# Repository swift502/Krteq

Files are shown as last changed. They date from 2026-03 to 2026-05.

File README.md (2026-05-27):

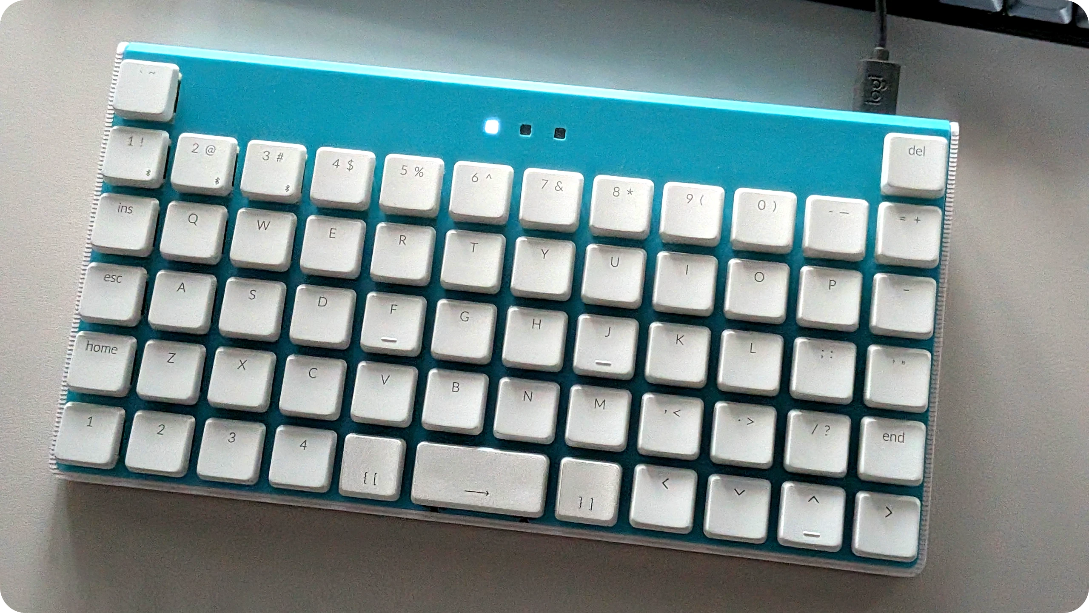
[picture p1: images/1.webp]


# Krteq





An extended 5x12 keyboard with 2 extra keys. Intended for ortho layouts with a shifted number row, allowing for the placement of the delete and tilde keys above their usual spots.

Krteq is a successor to [Krtkus](https://github.com/swift502/Krtkus), learning from its lessons to make a design that's easier to build, more maintainable, better encapsulated and overall a more complete product.

### Features

- Low profile
- Hotswap
- White backlight (only breathing effect)
- QMK/VIA compatible
- Gateron KS-33B (GLP 3.0) switches
- 3D printed case with a 7 degree tilt
- Tray mount PCB, integrated plate
- 233mm × 125mm × 30mm

Connecting the keyboard to [usevia.app](https://usevia.app) requires manually uploading the [design file](production/krteq_via.json) in the design tab.

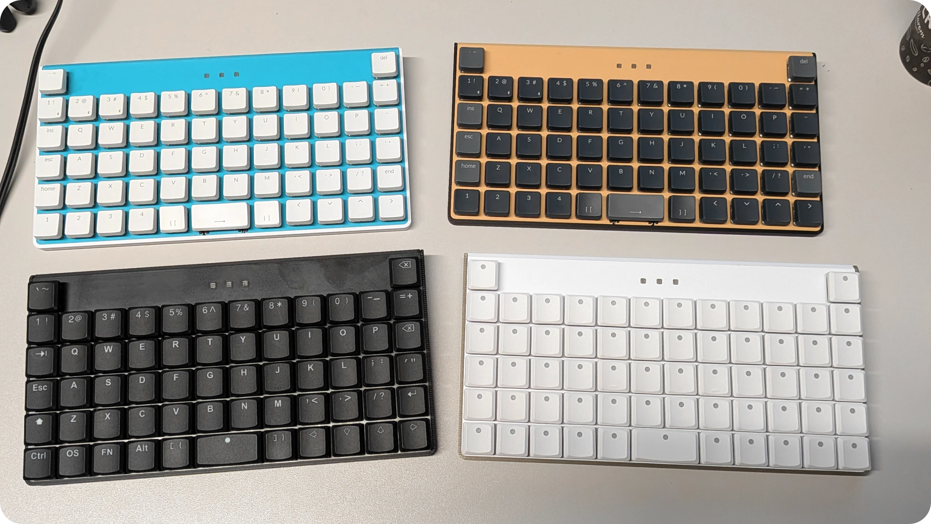
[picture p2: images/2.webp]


## PCB

The Kicad 10 project can be found in [source/kicad](source/kicad). All parts are SMD. The PCB is intended to be ordered pre-assembled for an easier, although more expensive build process.

To generate fabrication files, open the Kicad project and use an export plugin provided by one of the PCB manufacturers you want to order from. The order process is then highly dependent on the manufacturer.

Suggested resistor values correspond to max safe LED brightness, which is later adjusted using software. Backlight intensity is controlled by QMK's backlight system, and indicator brightness is adjustable via custom PWM code.

### Suggested BOM

| Part | Manufacturer Part Number |
|---|---|
| Switch Diode | 1N4148W |
| Backlight LED | MHT151WDT |
| GSD NMOS | HX2302A |
| R82Ω | 0603WAF820JT5E |
| R330Ω | 0603WAF3300T5E |
| R470Ω | 0603WAF4700T5E |
| R10kΩ | 0603WAF1002T5E |
| Switch socket | CPG151101S11-16 |

## Case

Case is designed non-destructively in Blender here [source/Krteq.blend](source/Krteq.blend), so it should be fairly easy to modify if needed. STL files for 3D printing can be found in [production/stl](production/stl). Tested with PLA, 0.15mm layer height, 100% infill.

You'll need to print at least 3 files. Top and bottom in one or two colors, and the LED cover strip using transparent filament.

The top part also has a "keychron" variant, which adjusts stabilizer cutouts for their non-standard [triangular stem design](https://www.keychron.com/blogs/news/the-design-details-of-our-keychron-low-profile-keyboard-stabilizers).

## Firmware

A pre-compiled firmware file can be found here [production/krteq_firmware.uf2](production/krteq_firmware.uf2).

QMK/VIA setup with a few custom features:

- custom `KRT_VOL` keycode for combined volume control
- pressing <kbd>LShift</kbd> + <kbd>RShift</kbd> + <kbd>B</kbd> enters bootloader mode
- pressing <kbd>LShift</kbd> + <kbd>RShift</kbd> + <kbd>C</kbd> reverts to the default keymap

### Compiling (Windows)

Install:

- Python: https://www.python.org/
- MSYS: https://msys.qmk.fm

Run the compile script:

```sh
python source/scripts/qmk_compile.py
```

### Flashing (Windows)

For the initial flash, hold the BOOTSEL button while connecting the Pico to a computer to have it show up as a storage device, then copy the compiled [firmware file](production/krteq_firmware.uf2) over to it.

Once flashed, you can trigger the bootloader mode again by simply pressing the <kbd>LShift</kbd> + <kbd>RShift</kbd> + <kbd>B</kbd> key combination.

## Build guide

### Parts

- [PCB](#pcb)
- [Case](#case)
- Raspberry Pi Pico
- 30cm (1ft) USB panel-mount extension cable
- 61x Gateron KS-33B (GLP 3.0) switches
- 61x MX low profile keycaps
- Gateron 2u low profile plate-mounted stabilizer
- 3x M2x6 flat head screw
- Rubber feet

### Assembly

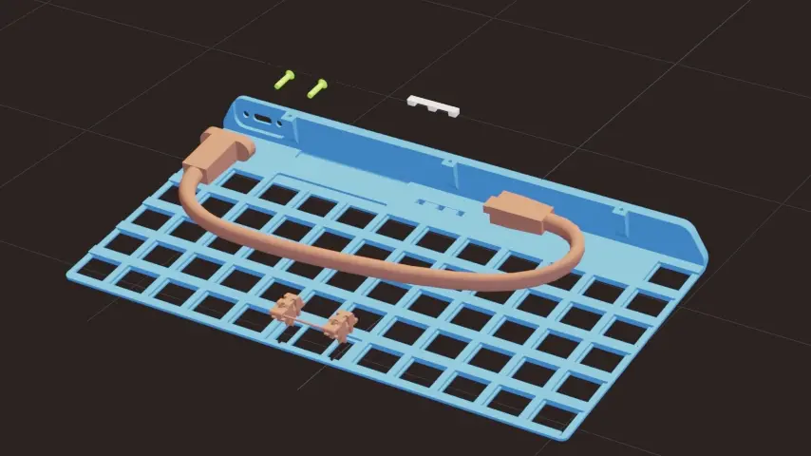
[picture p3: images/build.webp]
(https://youtu.be/iH0en77GBfo)


Assuming you get the PCB pre-assembled, the only thing left to solder is the MCU. I recommend using a socket header for easy Pico replacement, but it can obviously be soldered directly as well.

1. Install the Pico onto the PCB (socketed or soldered)
2. Attach the indicator LED cover strip to the top case
3. Attach the 2u stabilizer to the top case
4. Push the corner switches through the top case and into the PCB sockets to hold the two parts together
5. Screw the panel mount cable to the case cutout and connect the other end to the Pico

> [!IMPORTANT]
> Now is your last chance to perform the initial [firmware flash](#flashing-windows). After this point the BOOTSEL button won't be accessible. I also recommend plugging the keyboard in and testing basic functionality. If you find an issue, it's still very easy to test connectivity or swap out the Pico.

6. Slide the top assembly into the bottom case rails
7. Screw the top and bottom cases together
8. Install the remaining switches and keycaps

And you're done!

## QnA

### Why the unusual KS-33B switches?

The idea was that ordering a pre-assembled PCB will be faster, cheaper and long-term more viable if it involves regular hotswap sockets, since they're always in stock and available in cheaper off-brand variants, unlike the Gateron low profile hotswap sockets, which are much less common. The fact that they also support regular MX switches is a nice bonus.

### So is this board compatible with high profile switches?

Footprint-wise, yes, but a compatible high-profile top case variant would have to be made, and I have no idea if the low profile stabilizer would be compatible with regular keycaps. So there's a few concerns, but theoretically it's possible.

### Why no RGB?

The simple backlighting was a lot safer and easier to implement. But now that I've confirmed it works, I'd love to implement proper RGB with all effects for the next revision.

### Who needs scroll lock?

I really wanted an LED for my custom letter accent input method. I wanted it to be an actual compose LED, which would be supported by QMK, but unfortunately not Windows. So ultimately the third LED ended up being a regular scroll lock. I use it as an indicator for my custom accent input method, but generally like it as a general purpose LED that can be used for custom functionality via AHK scripts.

## Documentation

### QMK

- Info.json: https://docs.qmk.fm/reference_info_json
- Keycodes: https://docs.qmk.fm/keycodes
- Default keymap: https://docs.qmk.fm/configurator_default_keymaps
- Backlight: https://docs.qmk.fm/features/backlight

### Kicad

Switch grid reference table:

| Grid | Size |
| --- | --- |
| Switch 1 | 19.05 |
| Switch 1/4 | 4.7625 |
| Switch 1/16 | 1.190625 |
| Switch 1/32 | 0.5953125 |
| Switch 1/64 | 0.29765625 |

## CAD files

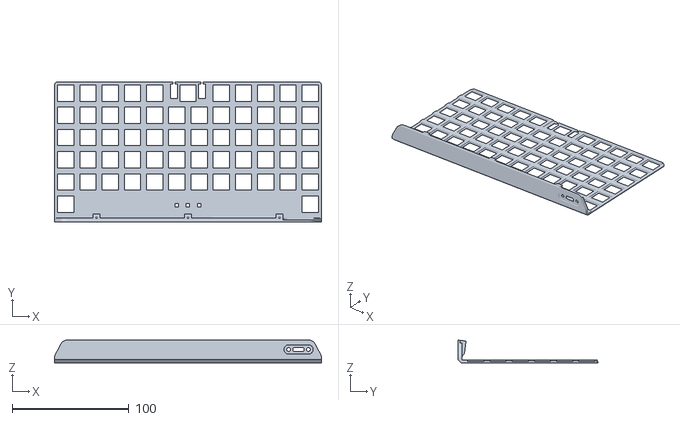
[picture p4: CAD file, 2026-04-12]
production/stl/top_keychron.stl
229.0 x 120.5 x 19.6

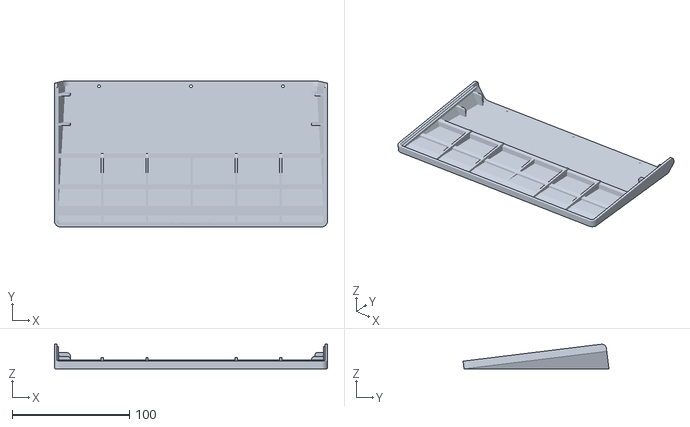
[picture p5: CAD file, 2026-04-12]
production/stl/bottom.stl
233.0 x 124.5 x 21.0

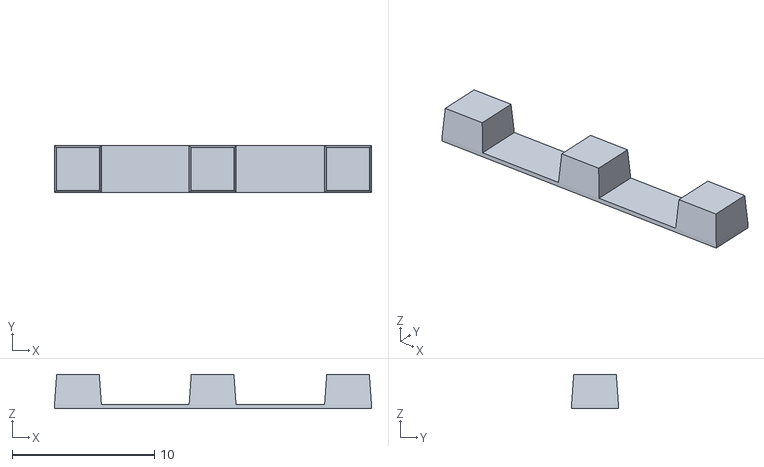
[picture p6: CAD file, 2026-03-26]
production/stl/led.stl
22.3 x 3.30 x 2.40

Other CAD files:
production/stl/top.stl
source/Krteq.blend

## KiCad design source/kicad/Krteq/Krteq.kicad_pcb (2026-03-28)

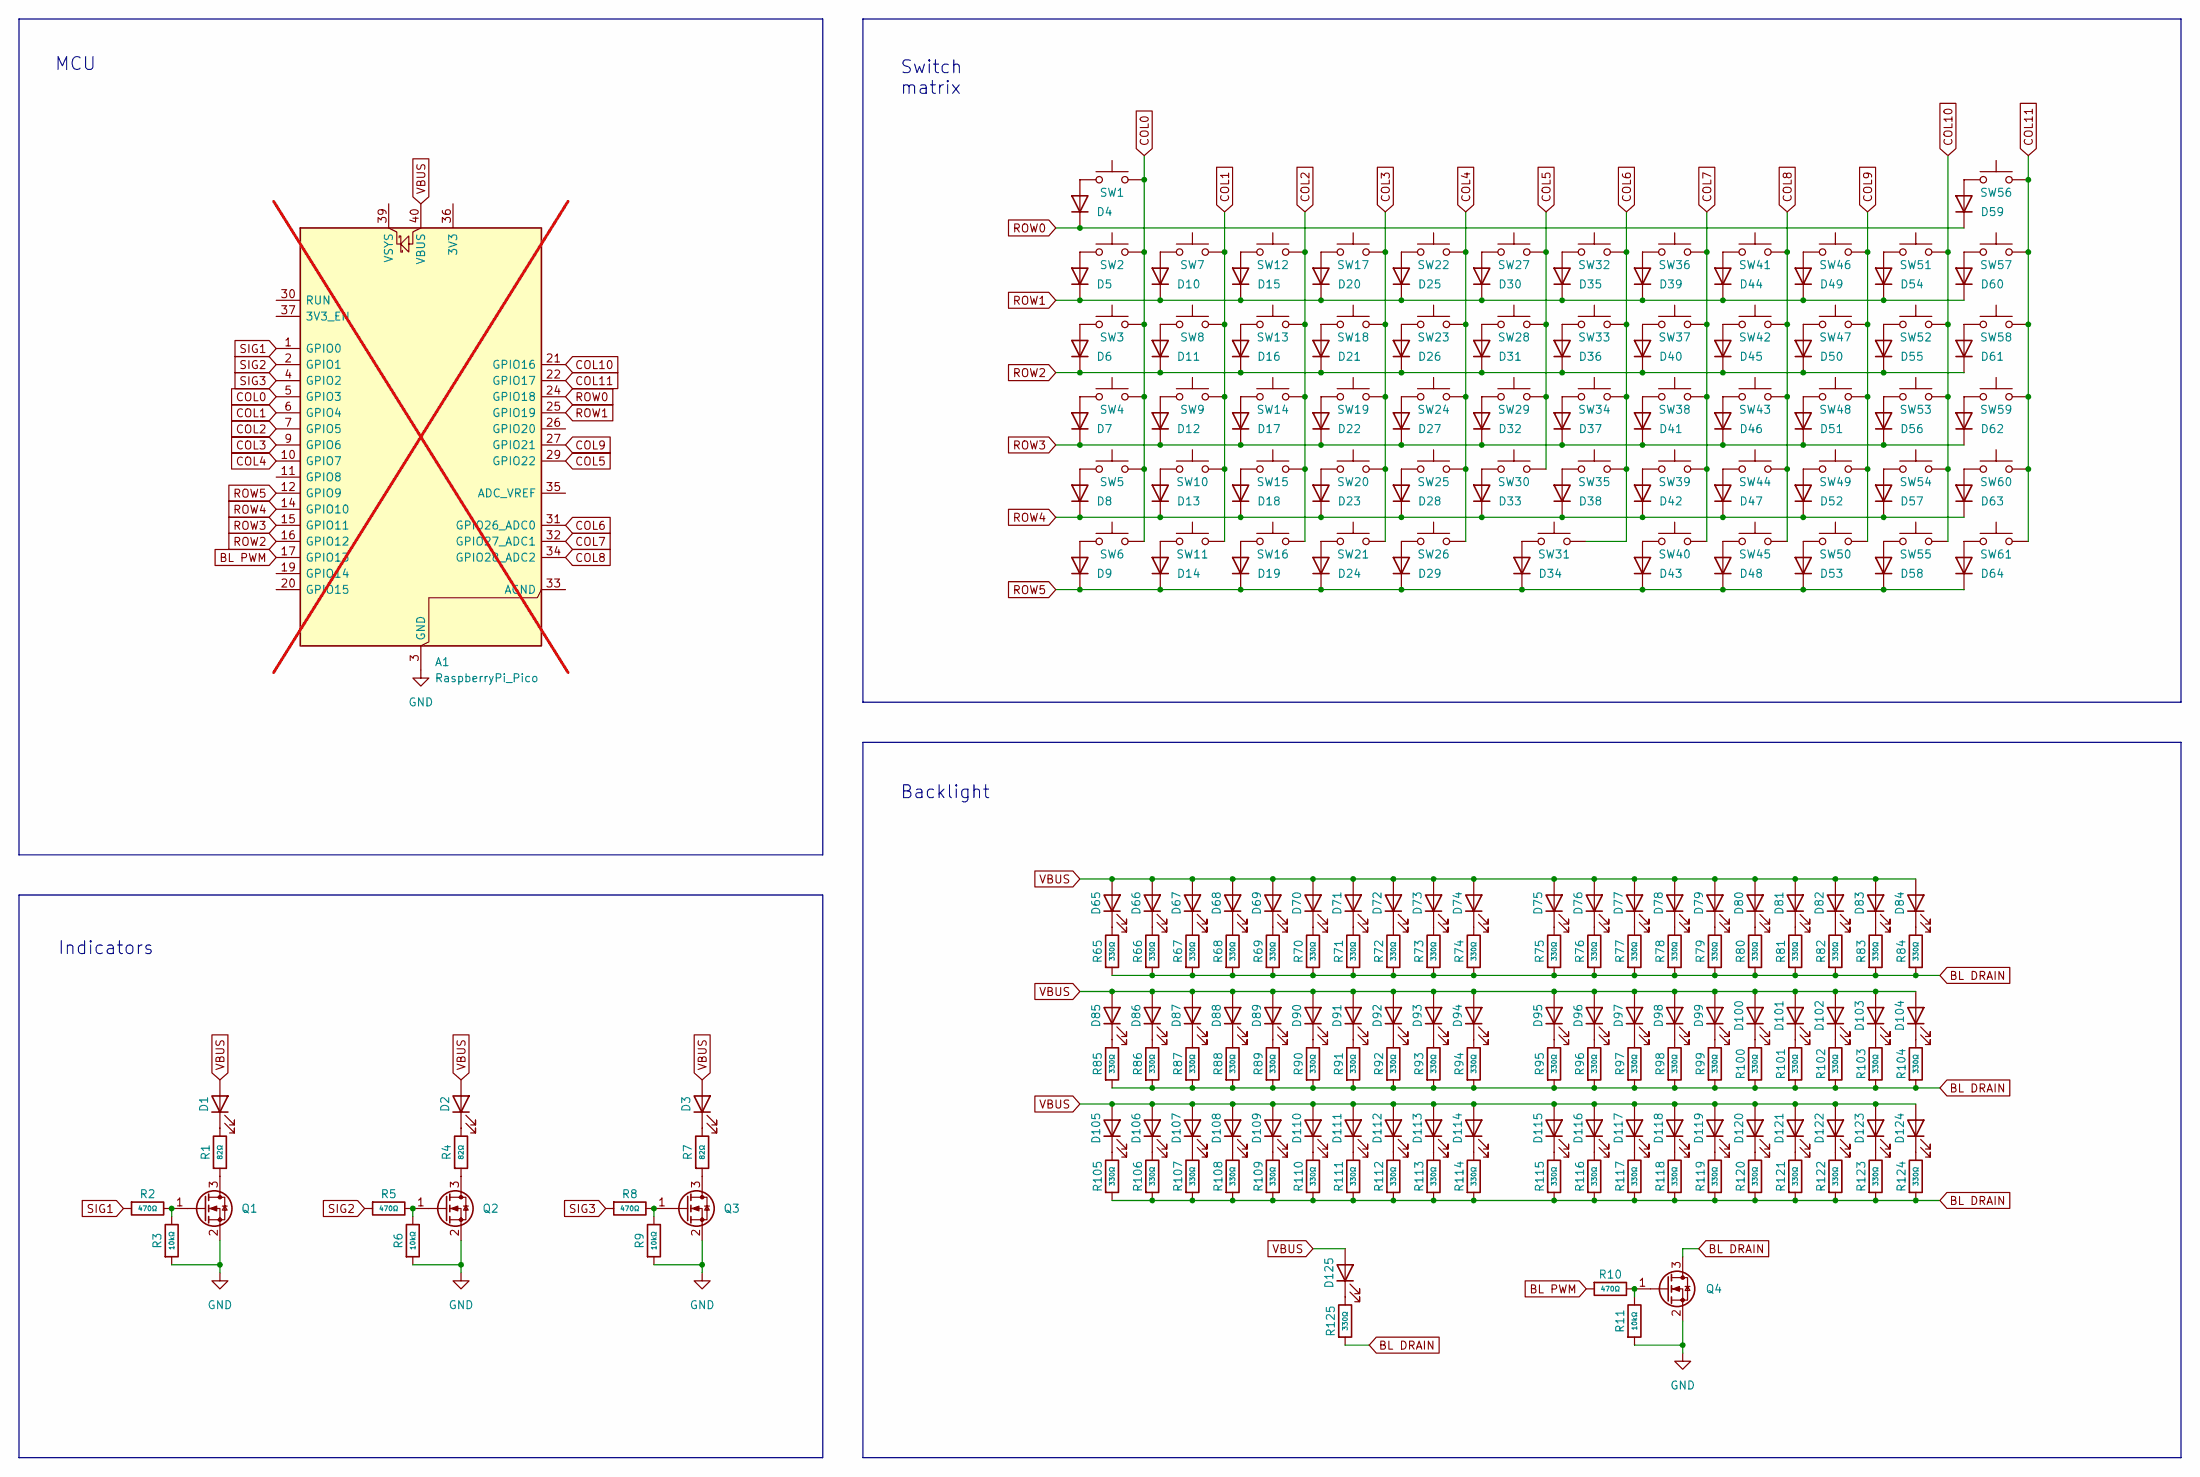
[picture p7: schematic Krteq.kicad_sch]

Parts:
A1: RaspberryPi_Pico; Raspberry Pi Pico; not fitted
D1, D2, D3, D65, D66, D67, D68, D69, D70, D71, D72, D73, D74, D75, D76, D77, D78, D79, D80, D81, D82, D83, D84, D85, D86, D87, D88, D89, D90, D91, D92, D93, D94, D95, D96, D97, D98, D99, D100, D101, D102, D103, D104, D105, D106, D107, D108, D109, D110, D111, D112, D113, D114, D115, D116, D117, D118, D119, D120, D121, D122, D123, D124, D125: LED; MHT151WDT; MPN MHT151WDT
D4, D5, D6, D7, D8, D9, D10, D11, D12, D13, D14, D15, D16, D17, D18, D19, D20, D21, D22, D23, D24, D25, D26, D27, D28, D29, D30, D31, D32, D33, D34, D35, D36, D37, D38, D39, D40, D41, D42, D43, D44, D45, D46, D47, D48, D49, D50, D51, D52, D53, D54, D55, D56, D57, D58, D59, D60, D61, D62, D63, D64: Diode; D_SOD-123; MPN 1N4148W
Q1, Q2, Q3, Q4: Q NMOS GSD; SOT-23; MPN HX2302A
R1, R4, R7: 82Ω; R_0603_1608Metric; MPN 0603WAF820JT5E
R2, R5, R8, R10: 470Ω; R_0603_1608Metric; MPN 0603WAF4700T5E
R3, R6, R9, R11: 10kΩ; R_0603_1608Metric; MPN 0603WAF1002T5E
R65, R66, R67, R68, R69, R70, R71, R72, R73, R74, R75, R76, R77, R78, R79, R80, R81, R82, R83, R84, R85, R86, R87, R88, R89, R90, R91, R92, R93, R94, R95, R96, R97, R98, R99, R100, R101, R102, R103, R104, R105, R106, R107, R108, R109, R110, R111, R112, R113, R114, R115, R116, R117, R118, R119, R120, R121, R122, R123, R124, R125: 330Ω; R_0603_1608Metric; MPN 0603WAF3300T5E
SW1, SW2, SW3, SW4, SW5, SW6, SW7, SW8, SW9, SW10, SW11, SW12, SW13, SW14, SW15, SW16, SW17, SW18, SW19, SW20, SW21, SW22, SW23, SW24, SW25, SW26, SW27, SW28, SW29, SW30, SW32, SW33, SW34, SW35, SW36, SW37, SW38, SW39, SW40, SW41, SW42, SW43, SW44, SW45, SW46, SW47, SW48, SW49, SW50, SW51, SW52, SW53, SW54, SW55, SW56, SW57, SW58, SW59, SW60, SW61: Switch; KS-33B Hotswap 1u; MPN CPG151101S11-16
SW31: Switch; KS-33B Hotswap 2u; MPN CPG151101S11-16

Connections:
BL DRAIN: Q4.3 (D), R65.2, R66.2, R67.2, R68.2, R69.2, R70.2, R71.2, R72.2, R73.2, R74.2, R75.2, R76.2, R77.2, R78.2, R79.2, R80.2, R81.2, R82.2, R83.2, R84.2, R85.2, R86.2, R87.2, R88.2, R89.2, R90.2, R91.2, R92.2, R93.2, R94.2, R95.2, R96.2, R97.2, R98.2, R99.2, R100.2, R101.2, R102.2, R103.2, R104.2, R105.2, R106.2, R107.2, R108.2, R109.2, R110.2, R111.2, R112.2, R113.2, R114.2, R115.2, R116.2, R117.2, R118.2, R119.2, R120.2, R121.2, R122.2, R123.2, R124.2, R125.2
BL PWM: A1.17 (GPIO13), R10.2
COL0: A1.5 (GPIO3), SW1.2, SW2.2, SW3.2, SW4.2, SW5.2, SW6.2
COL1: A1.6 (GPIO4), SW7.2, SW8.2, SW9.2, SW10.2, SW11.2
COL2: A1.7 (GPIO5), SW12.2, SW13.2, SW14.2, SW15.2, SW16.2
COL3: A1.9 (GPIO6), SW17.2, SW18.2, SW19.2, SW20.2, SW21.2
COL4: A1.10 (GPIO7), SW22.2, SW23.2, SW24.2, SW25.2, SW26.2
COL5: A1.29 (GPIO22), SW27.2, SW28.2, SW29.2, SW30.2
COL6: A1.31 (GPIO26_ADC0), SW31.2, SW32.2, SW33.2, SW34.2, SW35.2
COL7: A1.32 (GPIO27_ADC1), SW36.2, SW37.2, SW38.2, SW39.2, SW40.2
COL8: A1.34 (GPIO28_ADC2), SW41.2, SW42.2, SW43.2, SW44.2, SW45.2
COL9: A1.27 (GPIO21), SW46.2, SW47.2, SW48.2, SW49.2, SW50.2
COL10: A1.21 (GPIO16), SW51.2, SW52.2, SW53.2, SW54.2, SW55.2
COL11: A1.22 (GPIO17), SW56.2, SW57.2, SW58.2, SW59.2, SW60.2, SW61.2
GND: A1.3 (GND), A1.8 (GND), A1.13 (GND), A1.18 (GND), A1.23 (GND), A1.28 (GND), A1.38 (GND), Q1.2 (S), Q2.2 (S), Q3.2 (S), Q4.2 (S), R3.2, R6.2, R9.2, R11.2
unnamed: D1.1 (K), R1.1
unnamed: D2.1 (K), R4.1
unnamed: D3.1 (K), R7.1
unnamed: D4.2 (A), SW1.1
unnamed: D5.2 (A), SW2.1
unnamed: D6.2 (A), SW3.1
unnamed: D7.2 (A), SW4.1
unnamed: D8.2 (A), SW5.1
unnamed: D9.2 (A), SW6.1
unnamed: D10.2 (A), SW7.1
unnamed: D11.2 (A), SW8.1
unnamed: D12.2 (A), SW9.1
unnamed: D13.2 (A), SW10.1
unnamed: D14.2 (A), SW11.1
unnamed: D15.2 (A), SW12.1
unnamed: D16.2 (A), SW13.1
unnamed: D17.2 (A), SW14.1
unnamed: D18.2 (A), SW15.1
unnamed: D19.2 (A), SW16.1
unnamed: D20.2 (A), SW17.1
unnamed: D21.2 (A), SW18.1
unnamed: D22.2 (A), SW19.1
unnamed: D23.2 (A), SW20.1
unnamed: D24.2 (A), SW21.1
unnamed: D25.2 (A), SW22.1
unnamed: D26.2 (A), SW23.1
unnamed: D27.2 (A), SW24.1
unnamed: D28.2 (A), SW25.1
unnamed: D29.2 (A), SW26.1
unnamed: D30.2 (A), SW27.1
unnamed: D31.2 (A), SW28.1
unnamed: D32.2 (A), SW29.1
unnamed: D33.2 (A), SW30.1
unnamed: D34.2 (A), SW31.1
unnamed: D35.2 (A), SW32.1
unnamed: D36.2 (A), SW33.1
unnamed: D37.2 (A), SW34.1
unnamed: D38.2 (A), SW35.1
unnamed: D39.2 (A), SW36.1
unnamed: D40.2 (A), SW37.1
unnamed: D41.2 (A), SW38.1
unnamed: D42.2 (A), SW39.1
unnamed: D43.2 (A), SW40.1
unnamed: D44.2 (A), SW41.1
unnamed: D45.2 (A), SW42.1
unnamed: D46.2 (A), SW43.1
unnamed: D47.2 (A), SW44.1
unnamed: D48.2 (A), SW45.1
unnamed: D49.2 (A), SW46.1
unnamed: D50.2 (A), SW47.1
unnamed: D51.2 (A), SW48.1
unnamed: D52.2 (A), SW49.1
unnamed: D53.2 (A), SW50.1
unnamed: D54.2 (A), SW51.1
unnamed: D55.2 (A), SW52.1
unnamed: D56.2 (A), SW53.1
unnamed: D57.2 (A), SW54.1
unnamed: D58.2 (A), SW55.1
unnamed: D59.2 (A), SW56.1
unnamed: D60.2 (A), SW57.1
unnamed: D61.2 (A), SW58.1
unnamed: D62.2 (A), SW59.1
unnamed: D63.2 (A), SW60.1
unnamed: D64.2 (A), SW61.1
unnamed: D65.1 (K), R65.1
unnamed: D66.1 (K), R66.1
unnamed: D67.1 (K), R67.1
unnamed: D68.1 (K), R68.1
unnamed: D69.1 (K), R69.1
unnamed: D70.1 (K), R70.1
unnamed: D71.1 (K), R71.1
unnamed: D72.1 (K), R72.1
unnamed: D73.1 (K), R73.1
unnamed: D74.1 (K), R74.1
unnamed: D75.1 (K), R75.1
unnamed: D76.1 (K), R76.1
unnamed: D77.1 (K), R77.1
unnamed: D78.1 (K), R78.1
unnamed: D79.1 (K), R79.1
unnamed: D80.1 (K), R80.1
unnamed: D81.1 (K), R81.1
unnamed: D82.1 (K), R82.1
unnamed: D83.1 (K), R83.1
unnamed: D84.1 (K), R84.1
unnamed: D85.1 (K), R85.1
unnamed: D86.1 (K), R86.1
unnamed: D87.1 (K), R87.1
unnamed: D88.1 (K), R88.1
unnamed: D89.1 (K), R89.1
unnamed: D90.1 (K), R90.1
unnamed: D91.1 (K), R91.1
unnamed: D92.1 (K), R92.1
unnamed: D93.1 (K), R93.1
unnamed: D94.1 (K), R94.1
unnamed: D95.1 (K), R95.1
unnamed: D96.1 (K), R96.1
unnamed: D97.1 (K), R97.1
unnamed: D98.1 (K), R98.1
unnamed: D99.1 (K), R99.1
unnamed: D100.1 (K), R100.1
unnamed: D101.1 (K), R101.1
unnamed: D102.1 (K), R102.1
unnamed: D103.1 (K), R103.1
unnamed: D104.1 (K), R104.1
unnamed: D105.1 (K), R105.1
unnamed: D106.1 (K), R106.1
unnamed: D107.1 (K), R107.1
unnamed: D108.1 (K), R108.1
unnamed: D109.1 (K), R109.1
unnamed: D110.1 (K), R110.1
unnamed: D111.1 (K), R111.1
unnamed: D112.1 (K), R112.1
unnamed: D113.1 (K), R113.1
unnamed: D114.1 (K), R114.1
unnamed: D115.1 (K), R115.1
unnamed: D116.1 (K), R116.1
unnamed: D117.1 (K), R117.1
unnamed: D118.1 (K), R118.1
unnamed: D119.1 (K), R119.1
unnamed: D120.1 (K), R120.1
unnamed: D121.1 (K), R121.1
unnamed: D122.1 (K), R122.1
unnamed: D123.1 (K), R123.1
unnamed: D124.1 (K), R124.1
unnamed: D125.1 (K), R125.1
unnamed: Q1.3 (D), R1.2
unnamed: Q1.1 (G), R2.1, R3.1
unnamed: Q2.3 (D), R4.2
unnamed: Q2.1 (G), R5.1, R6.1
unnamed: Q3.3 (D), R7.2
unnamed: Q3.1 (G), R8.1, R9.1
unnamed: Q4.1 (G), R10.1, R11.1
ROW0: A1.24 (GPIO18), D4.1 (K), D59.1 (K)
ROW1: A1.25 (GPIO19), D5.1 (K), D10.1 (K), D15.1 (K), D20.1 (K), D25.1 (K), D30.1 (K), D35.1 (K), D39.1 (K), D44.1 (K), D49.1 (K), D54.1 (K), D60.1 (K)
ROW2: A1.16 (GPIO12), D6.1 (K), D11.1 (K), D16.1 (K), D21.1 (K), D26.1 (K), D31.1 (K), D36.1 (K), D40.1 (K), D45.1 (K), D50.1 (K), D55.1 (K), D61.1 (K)
ROW3: A1.15 (GPIO11), D7.1 (K), D12.1 (K), D17.1 (K), D22.1 (K), D27.1 (K), D32.1 (K), D37.1 (K), D41.1 (K), D46.1 (K), D51.1 (K), D56.1 (K), D62.1 (K)
ROW4: A1.14 (GPIO10), D8.1 (K), D13.1 (K), D18.1 (K), D23.1 (K), D28.1 (K), D33.1 (K), D38.1 (K), D42.1 (K), D47.1 (K), D52.1 (K), D57.1 (K), D63.1 (K)
ROW5: A1.12 (GPIO9), D9.1 (K), D14.1 (K), D19.1 (K), D24.1 (K), D29.1 (K), D34.1 (K), D43.1 (K), D48.1 (K), D53.1 (K), D58.1 (K), D64.1 (K)
SIG1: A1.1 (GPIO0), R2.2
SIG2: A1.2 (GPIO1), R5.2
SIG3: A1.4 (GPIO2), R8.2
VBUS: A1.40 (VBUS), D1.2 (A), D2.2 (A), D3.2 (A), D65.2 (A), D66.2 (A), D67.2 (A), D68.2 (A), D69.2 (A), D70.2 (A), D71.2 (A), D72.2 (A), D73.2 (A), D74.2 (A), D75.2 (A), D76.2 (A), D77.2 (A), D78.2 (A), D79.2 (A), D80.2 (A), D81.2 (A), D82.2 (A), D83.2 (A), D84.2 (A), D85.2 (A), D86.2 (A), D87.2 (A), D88.2 (A), D89.2 (A), D90.2 (A), D91.2 (A), D92.2 (A), D93.2 (A), D94.2 (A), D95.2 (A), D96.2 (A), D97.2 (A), D98.2 (A), D99.2 (A), D100.2 (A), D101.2 (A), D102.2 (A), D103.2 (A), D104.2 (A), D105.2 (A), D106.2 (A), D107.2 (A), D108.2 (A), D109.2 (A), D110.2 (A), D111.2 (A), D112.2 (A), D113.2 (A), D114.2 (A), D115.2 (A), D116.2 (A), D117.2 (A), D118.2 (A), D119.2 (A), D120.2 (A), D121.2 (A), D122.2 (A), D123.2 (A), D124.2 (A), D125.2 (A)

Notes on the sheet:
Backlight
Switch matrix
Indicators
MCU

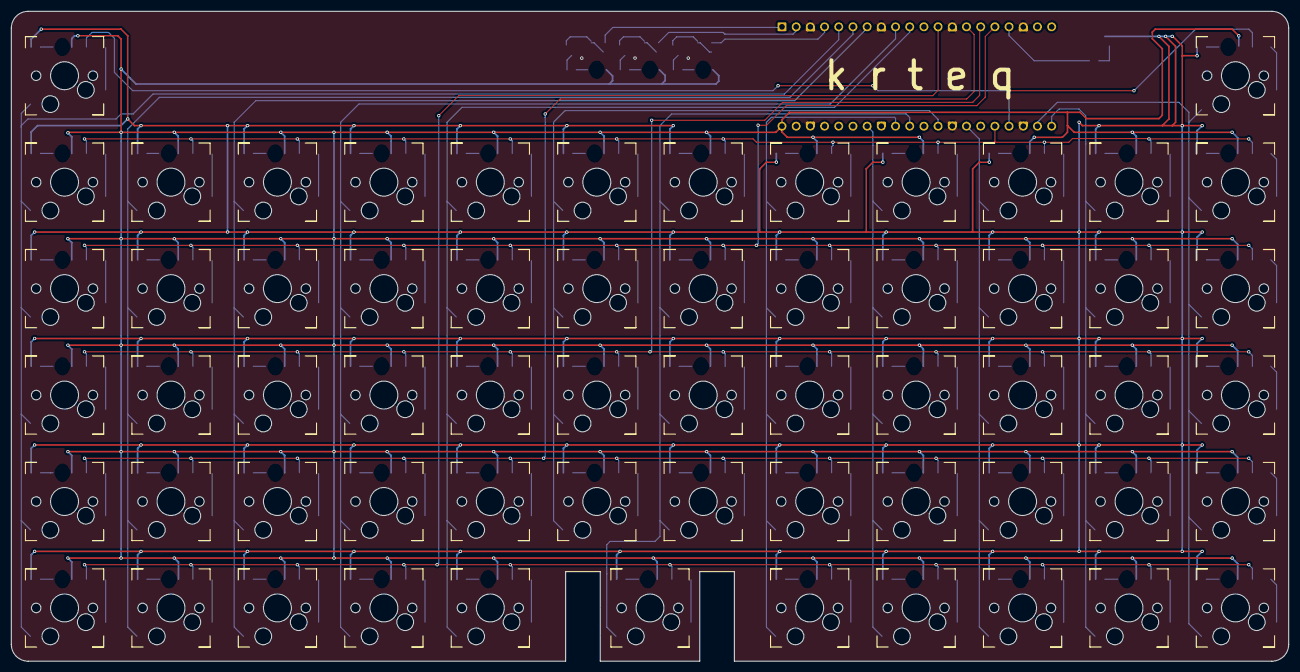
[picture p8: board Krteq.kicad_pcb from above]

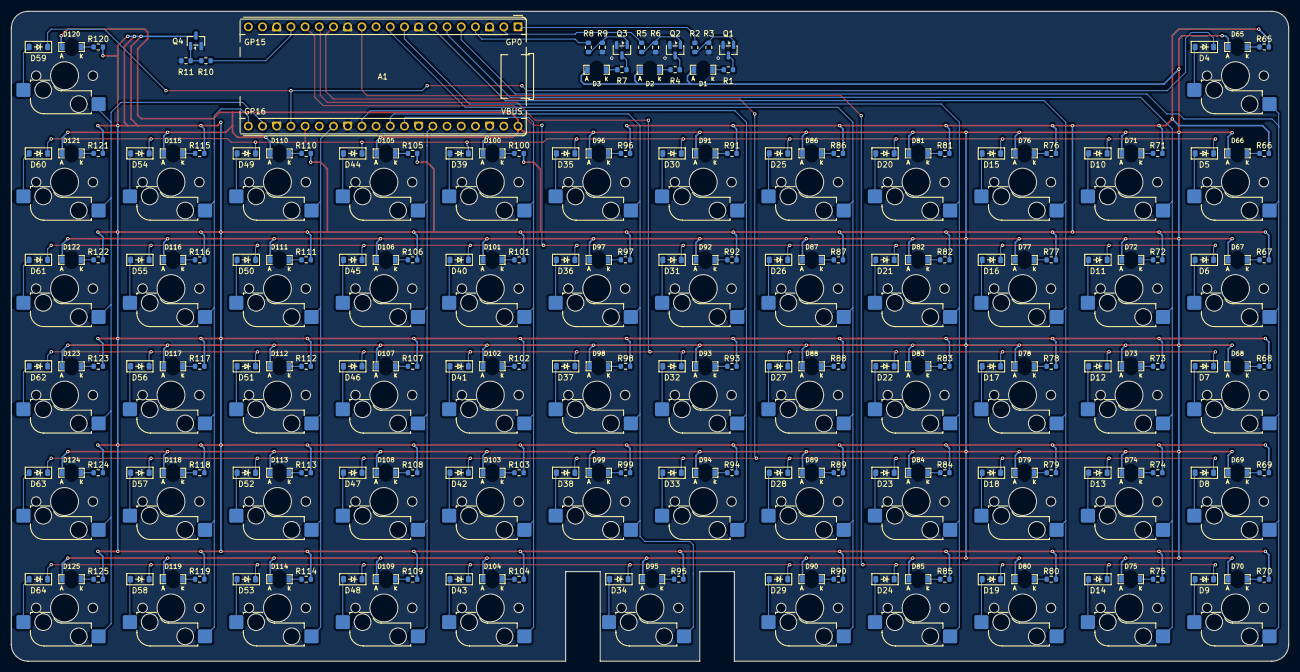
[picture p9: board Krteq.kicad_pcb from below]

Board: 2 copper layers, 228.6 x 116.3 mm, 263 parts (263 on the bottom side), 157 nets.

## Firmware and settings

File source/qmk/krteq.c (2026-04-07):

#include QMK_KEYBOARD_H
#include "hal.h"

// PWM0 A - GP0 (Num Lock)
// PWM0 B - GP1 (Caps Lock)
static PWMConfig pwm0_cfg = {
    .frequency = 1000000,
    .period = 511,
    .callback = NULL,
    .channels = {
        {PWM_OUTPUT_ACTIVE_HIGH, NULL},
        {PWM_OUTPUT_ACTIVE_HIGH, NULL}
    }
};

// PWM1 A - GP2 (Scroll Lock)
static PWMConfig pwm1_cfg = {
    .frequency = 1000000,
    .period = 511,        
    .callback = NULL,
    .channels = {
        {PWM_OUTPUT_ACTIVE_HIGH, NULL},
        {PWM_OUTPUT_DISABLED, NULL}
    }
};

bool process_record_kb(uint16_t keycode, keyrecord_t *record)
{
    uint8_t mods = get_mods();
    bool double_shift = (mods & MOD_MASK_SHIFT) == MOD_MASK_SHIFT;

    switch (keycode)
    {
        case KRT_VOL:
            if (record->event.pressed)
            {
                if (mods & MOD_MASK_CTRL)
                {
                    host_consumer_send(AUDIO_MUTE);
                }
                else if (mods & MOD_MASK_SHIFT)
                {
                    host_consumer_send(AUDIO_VOL_UP);
                }
                else
                {
                    host_consumer_send(AUDIO_VOL_DOWN);
                }
            }
            else
            {
                host_consumer_send(0);
            }
            return false;

        case KC_B:
            if (record->event.pressed && double_shift)
            {
                reset_keyboard();
                return false;
            }
            break;

        case KC_C:
            if (record->event.pressed && double_shift)
            {
                eeconfig_disable();
                soft_reset_keyboard();
                return false;
            }
            break;
    }

    return process_record_user(keycode, record);
}

void keyboard_post_init_kb(void)
{
    // 2.19.2. Function Select (PWM)
    // https://pip-assets.raspberrypi.com/categories/814-rp2040/documents/RP-008371-DS-1-rp2040-datasheet.pdf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
    palSetLineMode(GP0, PAL_MODE_ALTERNATE(4));
    palSetLineMode(GP1, PAL_MODE_ALTERNATE(4));
    palSetLineMode(GP2, PAL_MODE_ALTERNATE(4));

    pwmStart(&PWMD0, &pwm0_cfg);
    pwmStart(&PWMD1, &pwm1_cfg);

    // Initialize off
    pwmEnableChannel(&PWMD0, 0, 0);
    pwmEnableChannel(&PWMD0, 1, 0);
    pwmEnableChannel(&PWMD1, 0, 0);
}

bool led_update_kb(led_t led_state)
{
    bool res = led_update_user(led_state);

    if (res)
    {
        pwmEnableChannel(&PWMD0, 0, led_state.num_lock ? 1 : 0);
        pwmEnableChannel(&PWMD0, 1, led_state.caps_lock ? 1 : 0);
        pwmEnableChannel(&PWMD1, 0, led_state.scroll_lock ? 1 : 0);
    }

    return res;
}

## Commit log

2026-01-11 mcu connect
    [Krtkus2.kicad_sch]
2026-01-13 more footprints
    [Krtkus2.kicad_sch]
2026-01-13 switch footprints
    [Krteq.kicad_sch]
2026-01-14 pcb update
    [Krteq.kicad_pcb, Krteq.kicad_sch]
2026-01-15 case v1
    [Krteq.blend, Krteq.kicad_pcb]
2026-01-15 switches fix
    [Krteq.kicad_pcb]
2026-01-15 blend edits
    [Krteq.blend]
2026-01-16 case updates
    [Krteq.blend, Krteq.kicad_pcb, Krteq.kicad_sch]
2026-01-16 case update
    [Krteq.blend, Krteq.kicad_pcb]
2026-01-17 angled back, cleanup
    [Krteq.blend]
2026-01-17 support beams
    [Krteq.blend]
2026-01-17 pcb placement
    [Krteq.blend, Krteq.kicad_pcb, Krteq.kicad_sch]
2026-01-18 3d models
    [Krteq.blend, Krteq.kicad_pcb]
2026-01-18 extend top by 2mm
    [Krteq.blend, Krteq.kicad_pcb]
2026-01-18 new LED design
    [Krteq.blend, Krteq.kicad_pcb, Krteq.kicad_sch]
2026-01-19 better clips
    [Krteq.blend]
2026-01-19 Part consolidation
    [Krteq.kicad_pcb, Krteq.kicad_sch]
2026-01-19 model fix
    [Krteq.blend]
2026-01-19 clip size
    [Krteq.blend]
2026-01-20 MCU cable distance
    [Krteq.blend, Krteq.kicad_pcb]
2026-01-22 67cm MCU gap
    [Krteq.blend, Krteq.kicad_pcb]
2026-01-22 LEDs v3
    [Krteq.blend]
2026-01-22 led thickness
    [Krteq.blend]
2026-01-23 dismantle clips
    [Krteq.blend]
2026-01-23 ref tweak
    [Krteq.blend]
2026-01-23 center leds, remove side clips
    [Krteq.blend, Krteq.kicad_pcb]
2026-01-24 mcu position
    [Krteq.blend]
2026-01-25 pcb v1
    [Krteq.kicad_pcb, Krteq.kicad_sch]
2026-01-25 socket cutouts fix
    [Krteq.blend, Krteq.kicad_pcb]
2026-01-26 17mm connector span
    [Krteq.blend]
2026-01-26 pcb update, led position fix
    [Krteq.blend, Krteq.kicad_pcb]
2026-01-27 diode fix
    [Krteq.kicad_pcb, Krteq.kicad_sch]
2026-01-28 indicators fix
    [Krteq.blend]
2026-02-04 Clippy case
    * init
    * thick
    * 2
    * model update
    * led pos
    * tweaks
    * led position, case improvements
    * tweaks
    * tweak
    * tweak
    * tweak
    * welding
    * zvetseni tolerance switch cutoutu +0.1mm do vsech stran
    * v2
    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
    [Krteq.blend, Krteq.kicad_pcb]
2026-02-14 V7 (#2)
    * v6
    * better footprints fix
    * qmk init
    * qmk 2
    * cache fix
    * qmk features
    * via, keymap, input lock
    * keymap
    * cleanup
    * cleanup
    * cleanup
    * condition
    * compile
    * cleanup
    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
    [Krteq.blend, Krteq.kicad_pcb]
2026-02-20 V10 (#3)
    * V8
    * readme
    * readme
    * readme
    * readme, fix
    * readme
    * readme
    * readme
    * readme
    * readme
    * V9
    * clips fix
    * fix
    * welds
    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
    [Krteq.blend]
2026-02-20 parametric bend
    [Krteq.blend]
2026-02-21 switch cutouts v2
    [Krteq.blend]
2026-02-21 prod files
    [case_bottom.stl, case_top.stl]
2026-02-24 clips 0.2mm
    [Krteq.blend]
2026-03-02 model update
    [Krteq.blend]
2026-03-02 front clips
    [Krteq.blend]
2026-03-03 replace R82 with 330s for indicator LEDs
    [Krteq.kicad_pcb, Krteq.kicad_sch]
2026-03-03 82 ohm revert
    [Krteq.kicad_pcb, Krteq.kicad_sch]
2026-03-03 led brightness test
2026-03-04 led intensity
2026-03-05 indicator experiments
    [Krteq.blend]
2026-03-21 V30x (#4)
    * rounded underside
    * update
    * clean param
    * no curve
    * underside cleanup
    * v30x
    * fixes
    * fixes
    * stab gap
    * front clip, cleanup
    * colors
    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
    [Krteq.blend]
2026-03-21 screw hole fix
    [Krteq.blend]
2026-03-21 clips fix
    [Krteq.blend]
2026-03-22 kicad 10
    [Krteq.kicad_pcb, Krteq.kicad_sch]
2026-03-23 weld fix
    [Krteq.blend]
2026-03-24 supports update
    [Krteq.blend]
2026-03-24 corner fix
    [Krteq.blend]
2026-03-24 bend supports fix
    [Krteq.blend]
2026-03-25 switch v1
    [Krteq.blend]
2026-03-26 Blender tool (#5)
    * blender tools 1
    * error reporting
    * edit
    * export
    * checkbox
    * export all
    * params
    * refactor, cleanup
    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
    [Bottom.stl, Krteq.blend, LED.stl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]
2026-03-27 1.9mm bottom screw hole
    [Krteq.blend, bottom.stl, bottom_keychron.stl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]
2026-03-27 kicad, readme
2026-03-28 pcb pico helpers, cleanup
    [Krteq.kicad_pcb]
2026-03-28 better silkscreen
    [Krteq.kicad_pcb, Krteq.kicad_sch]
2026-03-31 screw holes tweaks
    [Krteq.blend, bottom.stl, bottom_keychron.stl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]
2026-04-11 hole 1.9 mm
    [Krteq.blend]
2026-10-18 update assembly guide
2026-10-18 footprints tweaks
2026-10-19 use 2.2 self tapping screw, use Everlight ARGB LED, pcb cleanup
2026-10-20 led clearance
2026-10-20 bom fix
2026-10-20 schematic cleanup
2026-10-26 case tweaks
2026-10-30 LED pad edits to match datasheet closer
2026-11-04 1.8 screw hole diameter
